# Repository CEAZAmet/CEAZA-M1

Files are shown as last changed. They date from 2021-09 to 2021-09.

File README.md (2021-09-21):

# Welcome to CEAZA-M1!
Wireless communication and memory backup expansion board for CEAZA MEGA.
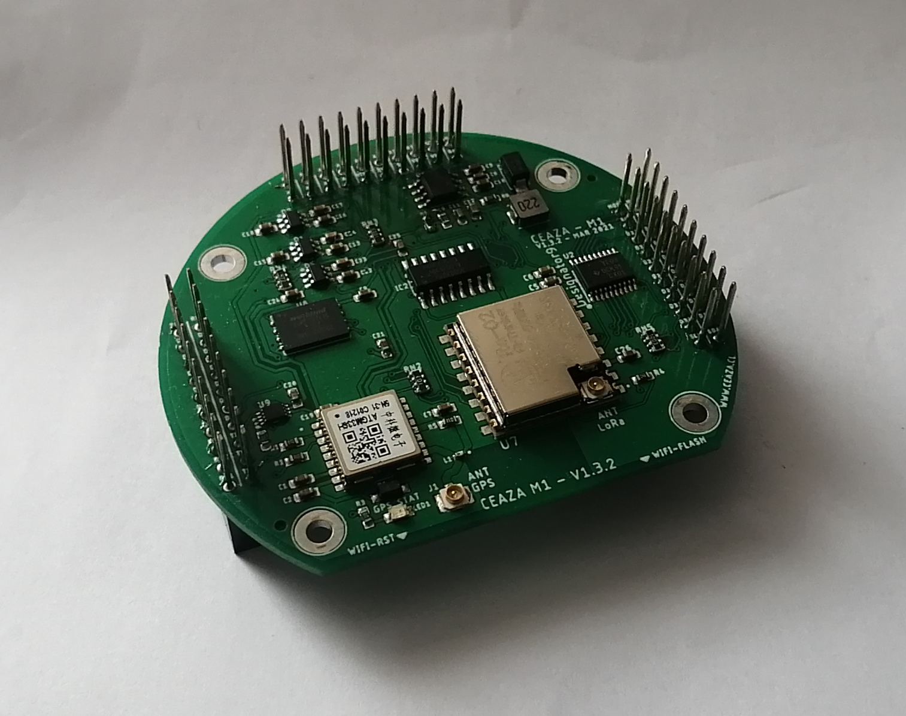
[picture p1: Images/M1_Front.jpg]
CEAZA M1 Board


## What is the CEAZA M1?

This design is an expansion board for CEAZA MEGA datalogger, which add the local wireless comumunication capability to the system.
The board Design integrates:
* An Ra-02 Ai-Thinker for 410-525MHz or Ra-01SH for 803MHz~930MHz LoRa Radio module.
* An ATGM336H-5N-31 GNSS GPS BDS positioning and navigation module.
* An ESP-12E WiFi module.
* A W25N01GVZEIG 1G-bit serial nand flash memory for redundant data storage.

All modules integratred are equiped with its respective power switch and power supply controlled by firmware for energy save when low power consumtions are required.
An on board jumper is included, ready to solder when the backup power source is required for GNSS module from permanent 3.3V available from CEAZA MEGA board, which increases 10uA the system power consumption.

The GNSS and WiFi modules share the same MCU UART2 thought an 74HC4052D analog multiplexer, which is controlled by firmware.

This board is pin compatible and should be connected to the CEAZA MEGA system to proper work.

## Documentation
A comprehensive documentation for well undertand, use or modify the CEAZA M1 board is available in our Wiki. In adition, we share with you the schematics diagrams, adns Arduino example codes.

## Quickstart guide
Install the M1 board in the CEAZA MEGA's bottom, make certain connection throuhg the boards by three 2 x 10 pin header terminals is rigth. 
Attach GNSS and LoRa antennas to the board, connect the power source 7 to 14 Vdc to the system.
Connect the CEAZA MEGA main board system to the host PC by mini-USB connector, open the Arduino ide software, select the Arduino Mega board and the correspondign COM port.

Open any of examples scketches and upload to the board.

# Contact and support
For all kinds of inquiries, please contact me to my e-mail address: adrian.gallardo@ceaza.cl

# Contributing
You are welcome to contribute to the development or improvement of M1 hardware design or example application codes. Feel free to submit a new pull request via github.

# Academic Context

# Licensing

# Disclaimer
Use M1 board and examples code at your own risk. We do not encourage any malicious use of our board.

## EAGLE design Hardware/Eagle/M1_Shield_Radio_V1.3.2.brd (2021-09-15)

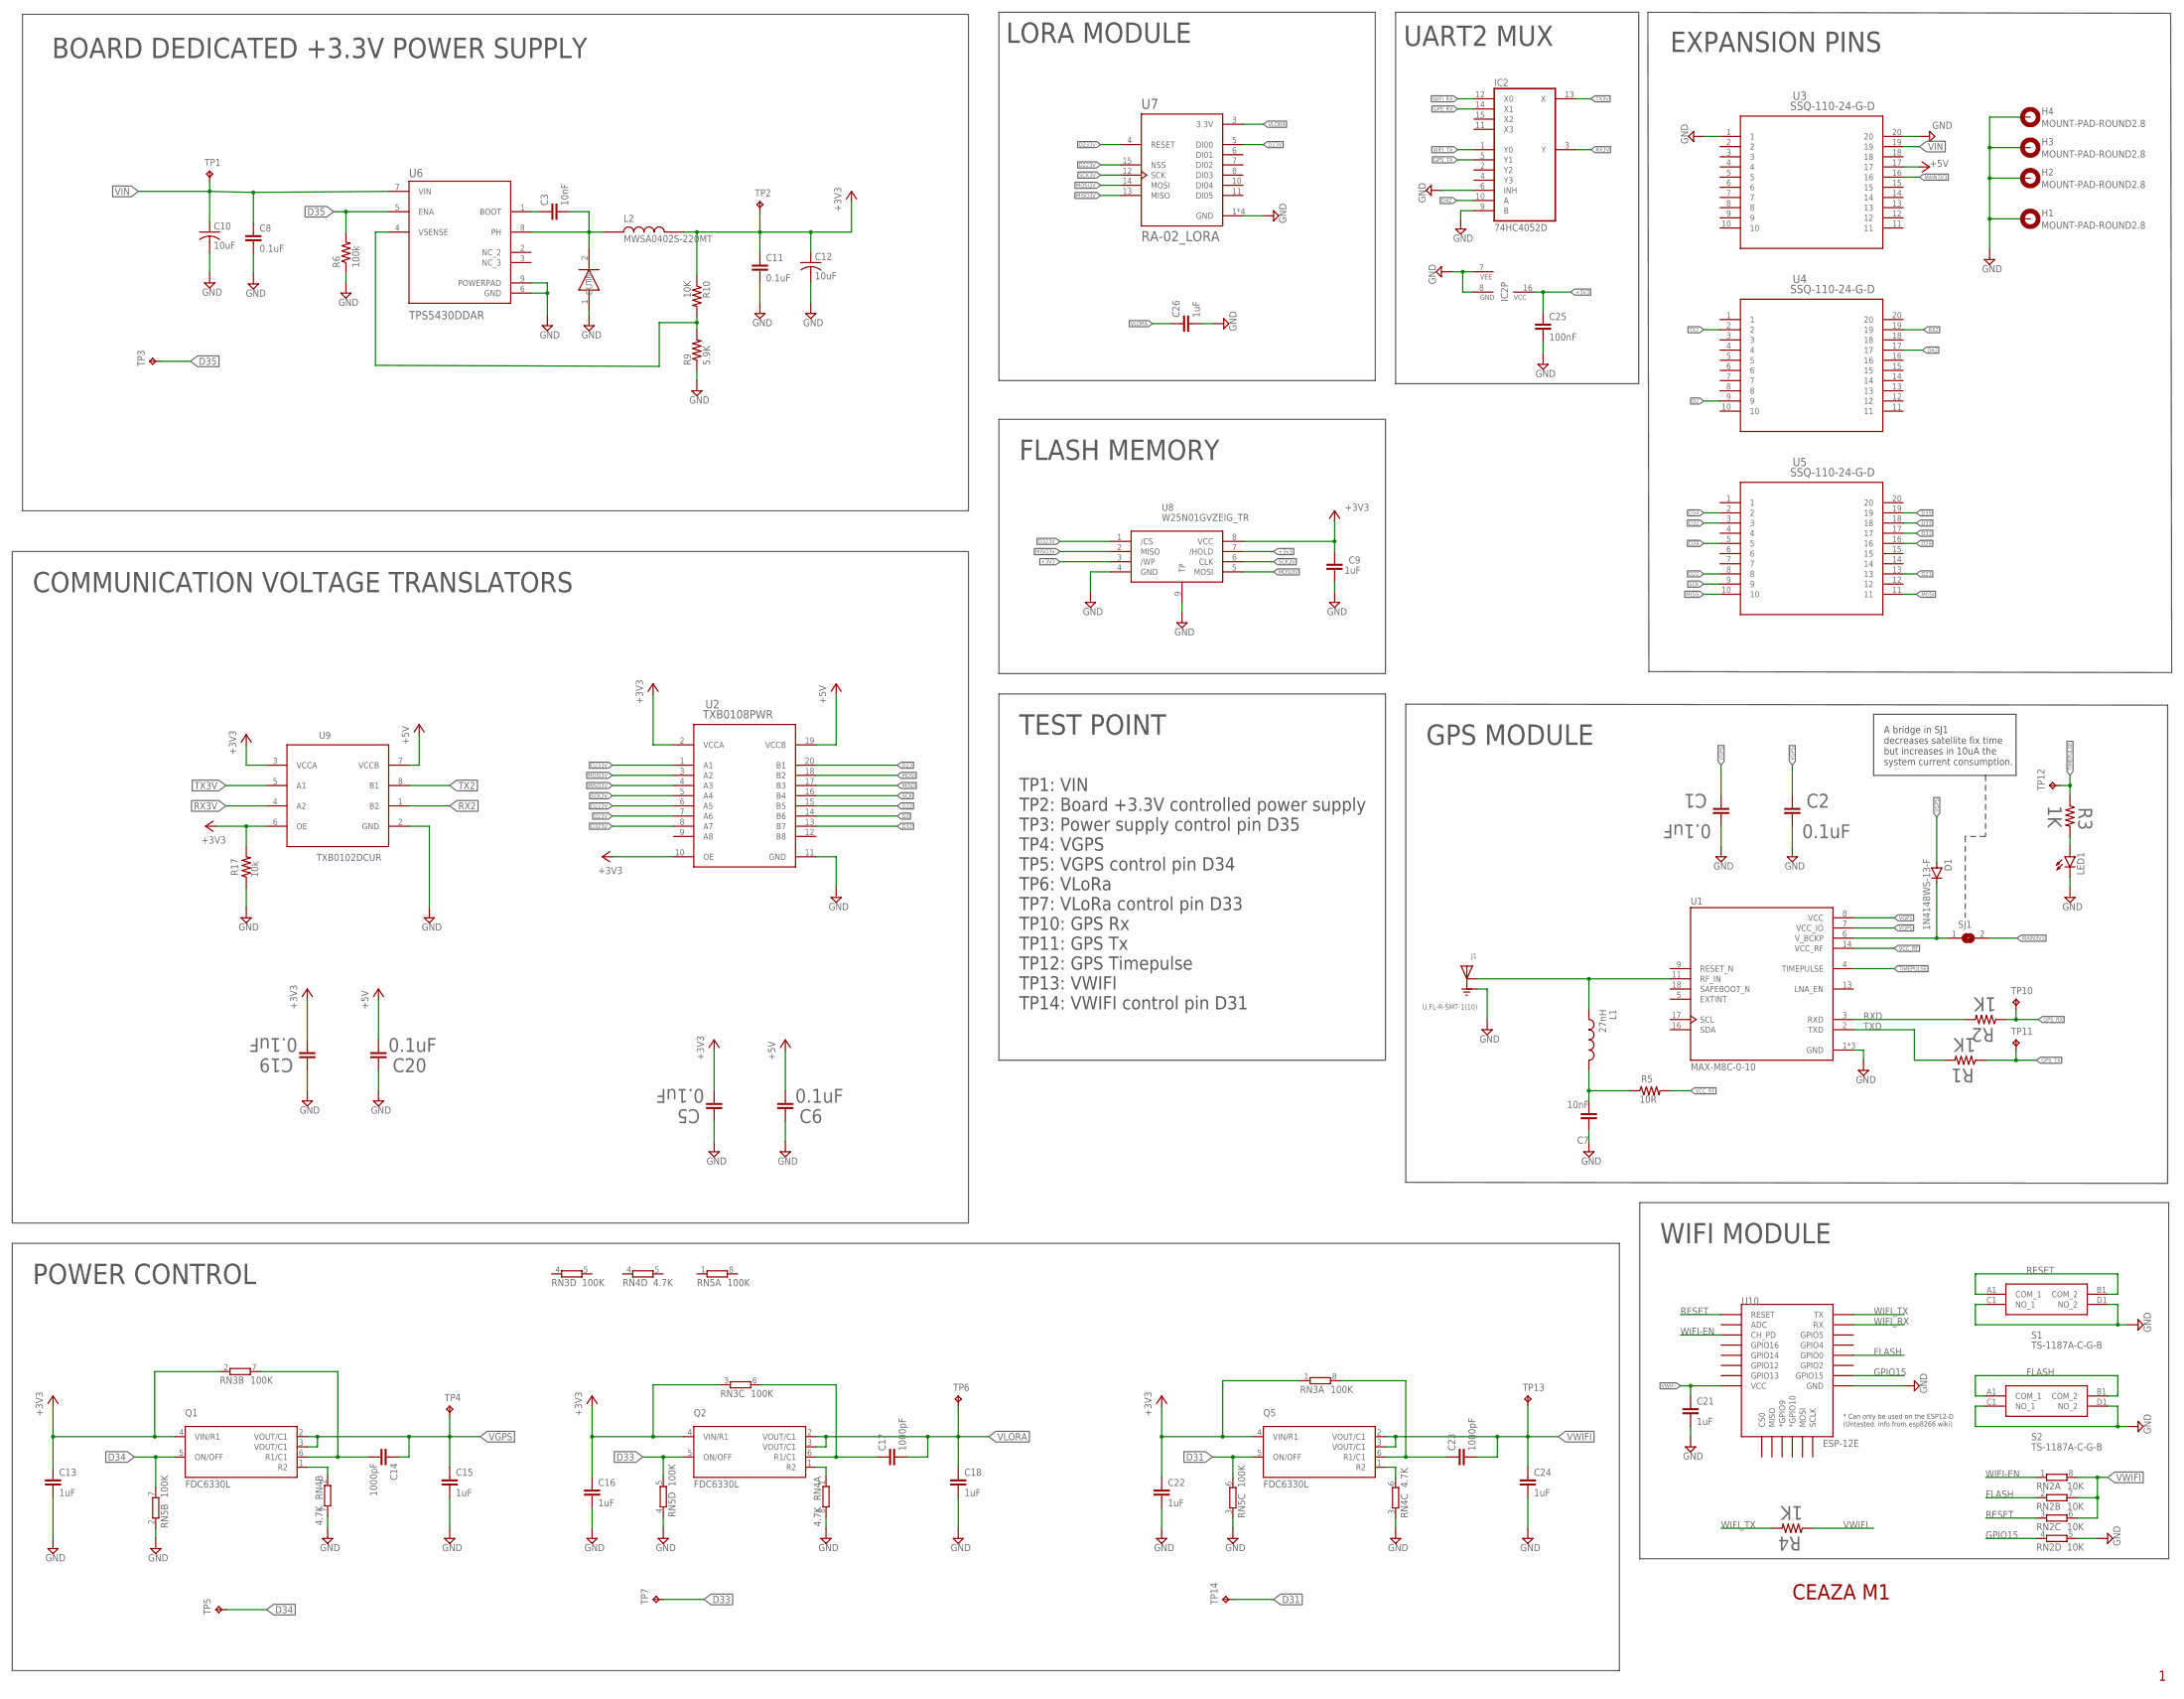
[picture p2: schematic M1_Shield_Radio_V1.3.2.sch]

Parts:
C1, C2, C5, C6, C8, C11, C19, C20: 0.1uF; C0603K
C3, C7: 10nF; C0603K
C9, C13, C15, C16, C18, C21, C22, C24, C26: 1uF; C0603K
C10, C12: 10uF; C0603K
C14, C17, C23: 1000pF; C0603K
C25: 100nF; C0603K
D1: 1N4148WS-13-F; SOD323-W
H1, H2, H3, H4: MOUNT-PAD-ROUND2.8; 2,8-PAD
IC2: 74HC4052D; SO16
J1: U.FL-R-SMT-1(10); HRS_U.FL-R-SMT-1(10)
L1: 27nH; INDC1005X55N
L2: MWSA0402S-220MT
LED1: LEDCHIP-LED0805; CHIP-LED0805
Q1, Q2, Q5: FDC6330L; SOT95P280X110-6N
R1, R2, R3, R4: 1K; R0603
R5: 10R; R0603
R6: 100k; R0603
R9: 5.9K; R0603
R10: 10K; R0603
R17: 10k; R0603
RN2: 10K; 0603-ARV
RN3, RN5: 100K; 0603-ARV
RN4: 4.7K; 0603-ARV
S1, S2: TS-1187A-C-G-B; TS1187ACGB
SJ1: SJ
TP1, TP2, TP3, TP4, TP5, TP6, TP7, TP10, TP11, TP12, TP13, TP14: TPB1,27; B1,27
U1: MAX-M8C-0-10; XCVR_MAX-M8C-0-10
U2: TXB0108PWR; PW0020A_N
U3, U4, U5: SSQ-110-24-G-D; 1-215307-0
U6: TPS5430DDAR; CONV_TPS5430DDAR
U7: RA-02_LORA; MODULE_RA-02_LORA
U8: W25N01GVZEIG_TR; W25N01GVZEIGTR
U9: TXB0102DCUR; DCU0008A_L
U10: ESP-12E; ESP12E-SMD
U$1: SMA-SS34

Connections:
+3V3: C5.2, C9.1, C11.1, C12.1, C13.1, C16.1, C19.2, C22.1, C25.1, IC2.16 (VCC), L2.P$2, Q1.4 (VIN/R1), Q2.4 (VIN/R1), Q5.4 (VIN/R1), R10.1, R17.2, RN3.1, RN3.2 (1), RN3.3 (1), TP2.TP, U2.2 (VCCA), U2.10 (OE), U8.3 (/WP), U8.7 (/HOLD), U8.8 (VCC), U9.3 (VCCA), U9.6 (OE)
+5V: C6.2, C20.2, U2.19 (VCCB), U3.17, U9.7 (VCCB)
D2: U2.14 (B6), U4.9
D22: U2.15 (B5), U5.8
D23: U2.20 (B1), U5.13
D23V: U2.7 (A6), U7.5 (DI00)
D28: U5.5
D29: U5.16
D31: Q5.5 (ON/OFF), RN5.6 (2), TP14.TP, U5.17
D32: U2.13 (B7), U5.3
D33: Q2.5 (ON/OFF), RN5.5 (2), TP7.TP, U5.18
D34: Q1.5 (ON/OFF), RN5.7 (2), TP5.TP, U5.2
D35: R6.2, TP3.TP, U5.19, U6.5 (ENA)
D42: IC2.10 (A), U4.17
D223V: U2.6 (A5), U7.15 (NSS)
D233V: U2.1 (A1), U7.4 (RESET)
D323V: U2.8 (A7), U8.1 (/CS)
FLASH: RN2.2 (1), S2.A1 (COM_1), S2.B1 (COM_2), U10.GPIO0
GND: C1.1, C2.1, C5.1, C6.1, C7.1, C8.2, C9.2, C10.2, C11.2, C12.2, C13.2, C15.2, C16.2, C18.2, C19.1, C20.1, C21.2, C22.2, C24.2, C25.2, C26.2, H1.B2,8, H2.B2,8, H3.B2,8, H4.B2,8, IC2.6 (INH), IC2.7 (VEE), IC2.8 (GND), IC2.9 (B), J1.1 (GND), J1.3 (GND), LED1.C, R6.1, R9.1, R17.1, RN2.5 (2), RN4.3 (1), RN4.7 (2), RN4.8 (2), RN5.2 (1), RN5.3 (1), RN5.4 (1), S1.C1 (NO_1), S1.D1 (NO_2), S2.C1 (NO_1), S2.D1 (NO_2), U1.1 (GND), U1.10 (GND), U1.12 (GND), U2.11 (GND), U3.1, U3.20, U6.6 (GND), U6.9 (POWERPAD), U7.1 (GND), U7.2 (GND), U7.9 (GND), U7.16 (GND), U8.4 (GND), U8.9 (TP), U9.2 (GND), U10.GND, U$1.1 (IN)
GPIO15: RN2.4 (1), U10.GPIO15
GPS_RX: IC2.14 (X1), R2.1, TP10.TP
GPS_TX: IC2.5 (Y1), R1.1, TP11.TP
MAIN3V3: SJ1.2, U3.16
MISO: U2.17 (B3), U5.10
MISO3V: U2.4 (A3), U7.13 (MISO), U8.2 (MISO)
MOSI: U2.18 (B2), U5.11
MOSI3V: U2.3 (A2), U7.14 (MOSI), U8.5 (MOSI)
unnamed: Q5.1 (R2), RN4.6 (2)
unnamed: LED1.A, R3.2
unnamed: J1.2 (SIG), L1.1, U1.11 (RF_IN)
unnamed: C7.2, L1.2, R5.1
unnamed: C3.1, U6.1 (BOOT)
unnamed: C14.2, Q1.6 (R1/C1), RN3.7 (2)
unnamed: C23.1, Q5.6 (R1/C1), RN3.8 (2)
unnamed: Q1.1 (R2), RN4.2 (1)
unnamed: Q2.1 (R2), RN4.1
unnamed: C17.1, Q2.6 (R1/C1), RN3.6 (2)
unnamed: D1.C, SJ1.1, U1.6 (V_BCKP)
unnamed: C3.2, L2.P$1, U6.8 (PH), U$1.2 (OUT)
RESET: RN2.3 (1), S1.A1 (COM_1), S1.B1 (COM_2), U10.RESET
RX2: U4.19, U9.1 (B2)
RX3V: IC2.3 (Y), U9.4 (A2)
RXD: R2.2, U1.3 (RXD)
SCK: U2.16 (B4), U5.9
SCK3V: U2.5 (A4), U7.12 (SCK), U8.6 (CLK)
TIMEPULSE: R3.1, TP12.TP, U1.4 (TIMEPULSE)
TX2: U4.2, U9.8 (B1)
TX3V: IC2.13 (X), U9.5 (A1)
TXD: R1.2, U1.2 (TXD)
VCC_RF: R5.2, U1.14 (VCC_RF)
VFB: R9.2, R10.2, U6.4 (VSENSE)
VGPS: C1.2, C2.2, C14.1, C15.1, D1.A, Q1.2 (VOUT/C1), Q1.3 (VOUT/C1), TP4.TP, U1.7 (VCC_IO), U1.8 (VCC)
VIN: C8.1, C10.1, TP1.TP, U3.19, U6.7 (VIN)
VLORA: C17.2, C18.1, C26.1, Q2.2 (VOUT/C1), Q2.3 (VOUT/C1), TP6.TP, U7.3 (3.3V)
VWIFI: C21.1, C23.2, C24.1, Q5.2 (VOUT/C1), Q5.3 (VOUT/C1), R4.1, RN2.6 (2), RN2.7 (2), RN2.8 (2), TP13.TP, U10.VCC
WIFI-EN: RN2.1, U10.CH_PD
WIFI_RX: IC2.12 (X0), U10.RXD0 (RX)
WIFI_TX: IC2.1 (Y0), R4.2, U10.TXD0 (TX)

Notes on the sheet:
BOARD DEDICATED +3.3V POWER SUPPLY
LORA MODULE
FLASH MEMORY
POWER CONTROL
GPS MODULE
COMMUNICATION VOLTAGE TRANSLATORS
EXPANSION PINS
TP1: VIN TP2: Board +3.3V controlled power supply TP3: Power supply control pin D35 TP4: VGPS TP5: VGPS control pin D34 TP6: VLoRa TP7: VLoRa control pin D33 TP10: GPS Rx TP11: GPS Tx TP12: GPS Timepulse TP13: VWIFI TP14: VWIFI control pin D31
TEST POINT
UART2 MUX
WIFI MODULE
A bridge in SJ1 decreases satellite fix time but increases in 10uA the system current consumption.
CEAZA M1

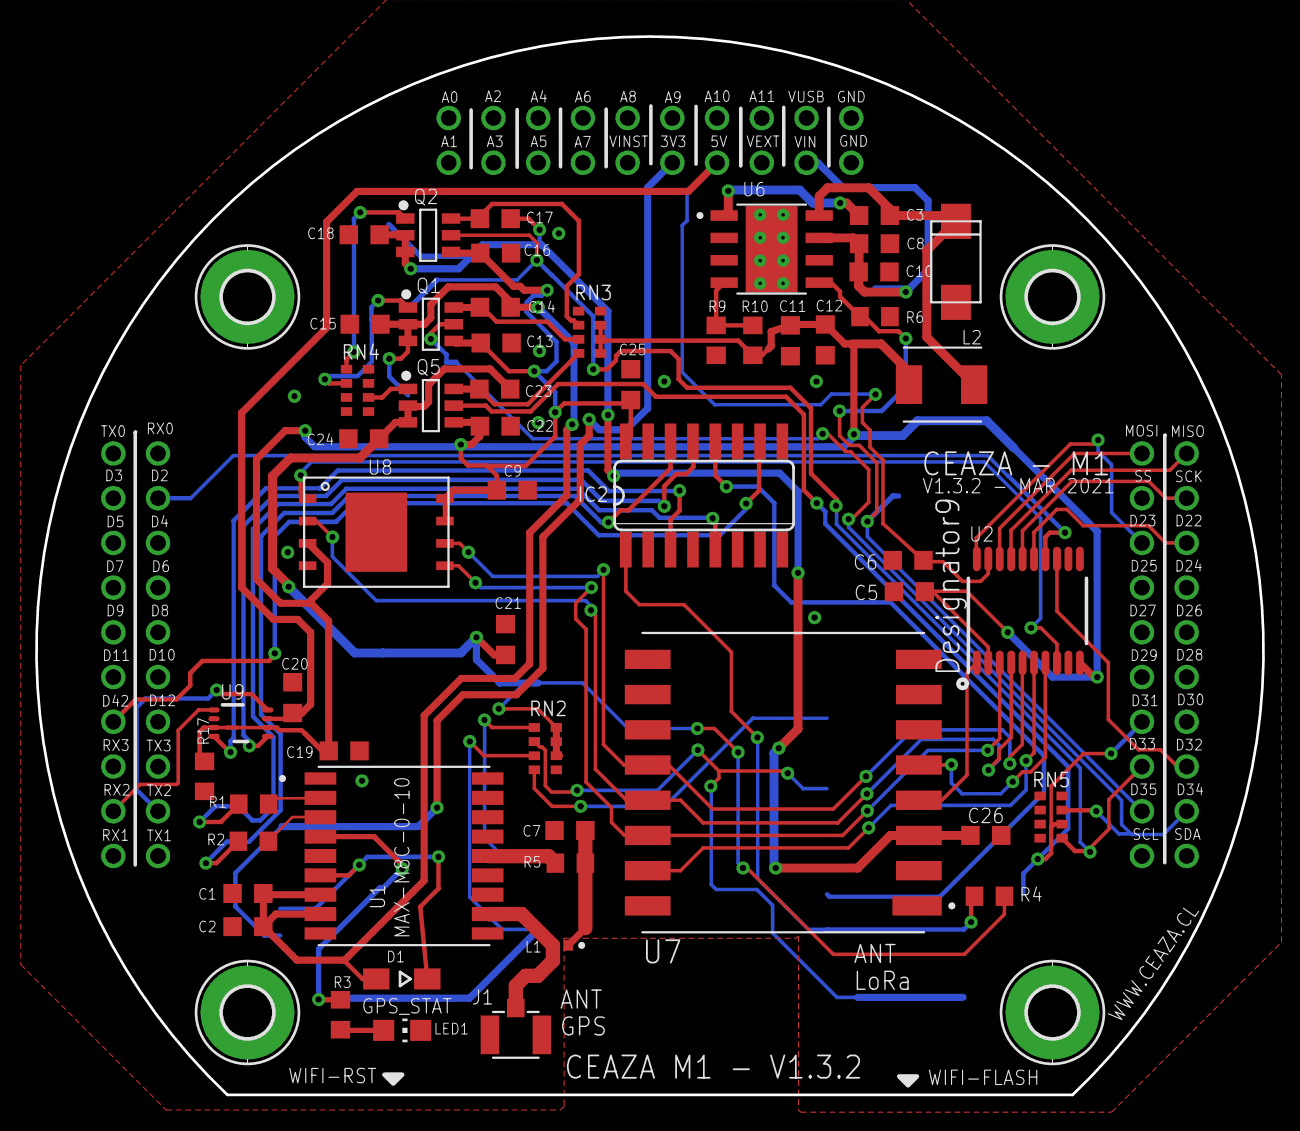
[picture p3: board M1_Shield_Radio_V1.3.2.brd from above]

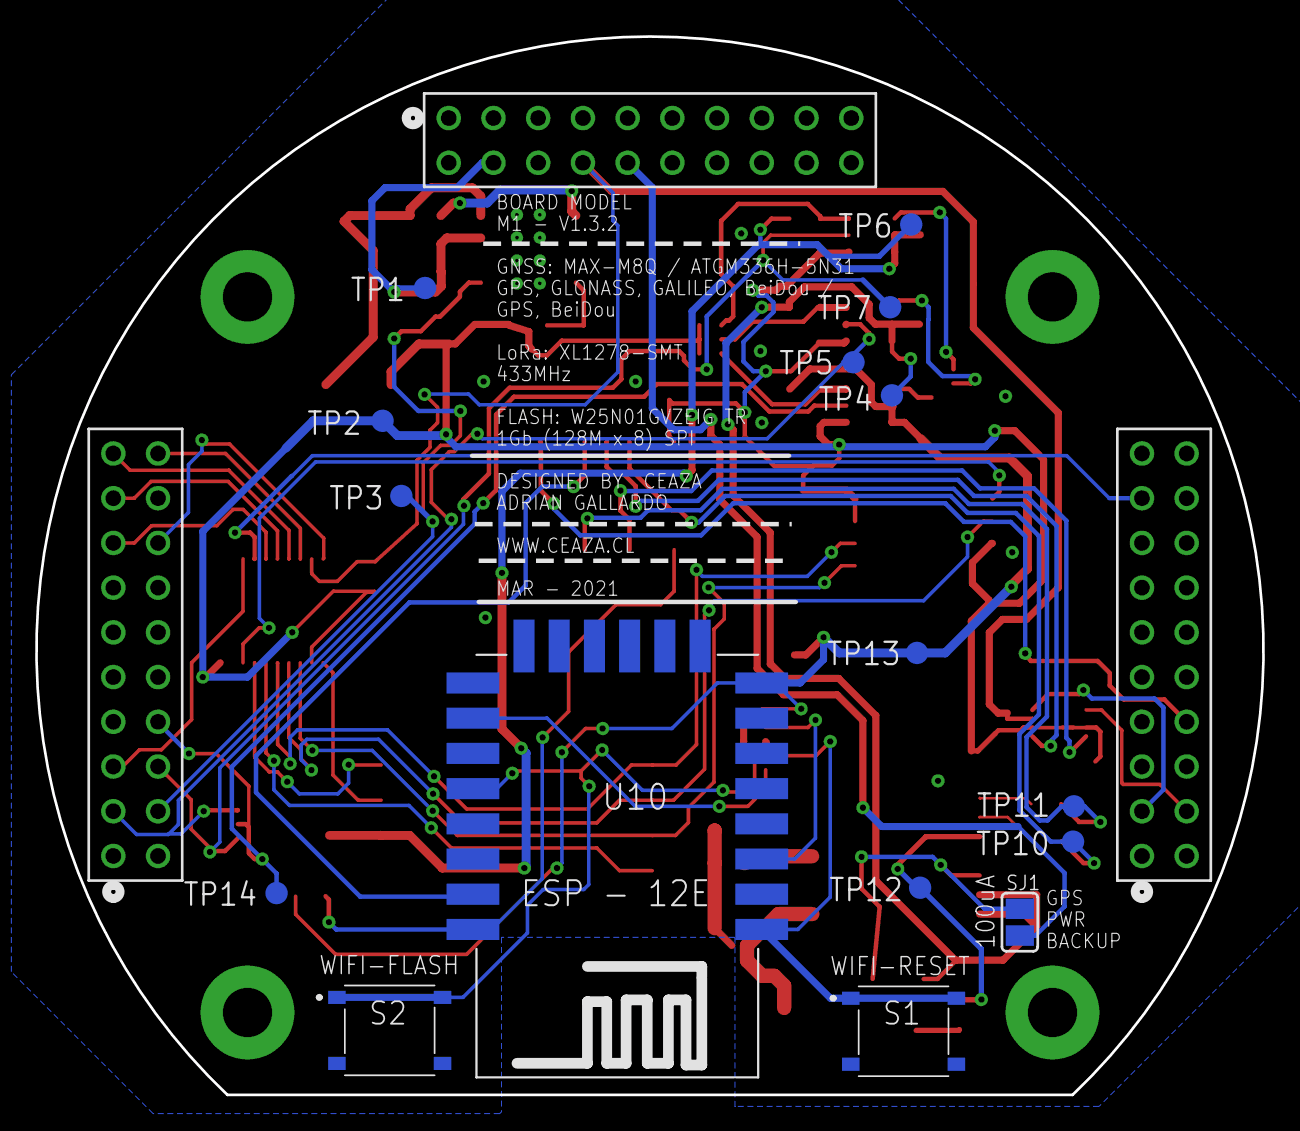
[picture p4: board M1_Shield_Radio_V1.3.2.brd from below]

Board: 2 copper layers, 69.7 x 60.1 mm, 77 parts (19 on the bottom side), 56 nets.

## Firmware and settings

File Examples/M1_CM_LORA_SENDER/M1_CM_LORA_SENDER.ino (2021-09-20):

/*
 * This sketch is an application example of LoRa.h and LowPwer.h with a 433MHz LoRa module
 * for data transmitting and go to sleep in CEAZA MEGA + M1 system
 * Is highly recommend do not use the M1 module without LoRa and GNSS antenas connected
 * to avoid damage the respective modules.
 * 
 * You have to intall LoRa library
 * https://github.com/sandeepmistry/arduino-LoRa
 * 
 * and LowPower library
 * https://github.com/rocketscream/Low-Power
 * 
 * Remember to select the "Arduino Mega or Mega2560" board for CEAZA MEGA
 */
#include <SPI.h>
#include <LoRa.h>
#include "LowPower.h"

// Pin definition
#define M1_3V3_EN_PIN   35
#define M1_VLORA_EN_PIN 33
#define LORA_SS_PIN     22
#define LORA_RESET_PIN  23
#define LORA_DIO0_PIN   2
#define FLASH_SS_PIN    32
#define SD_SS_PIN       53
#define LED_PIN         13

// LoRa setup definition
#define LORA_FREC       433E6   //(`433E6`, `866E6`, `915E6`)
#define LORA_SF         9       //6 to 12
#define LORA_TX_POW     18      //2 to 20
#define LORA_BANDWIDTH  125E3   //`7.8E3`, `10.4E3`, `15.6E3`, `20.8E3`, `31.25E3`, `41.7E3`, `62.5E3`, `125E3`, and `250E3`.

// Message counter
int counter = 0;

void setup() {
  // MCU I/O definition
  pinMode(FLASH_SS_PIN,OUTPUT);digitalWrite(FLASH_SS_PIN,HIGH);       // SPI Flash communication disabled
  pinMode(SD_SS_PIN,OUTPUT);digitalWrite(SD_SS_PIN,HIGH);             // SPI microSD communication disabled
  pinMode(LED_PIN,OUTPUT);digitalWrite(LED_PIN,LOW);                  // Built in LED off
  pinMode(M1_3V3_EN_PIN,OUTPUT);digitalWrite(M1_3V3_EN_PIN,HIGH);     // dedicated M1 3.3V power supply on 
  delay(10);                                                          // step down converter Start time
  pinMode(M1_VLORA_EN_PIN,OUTPUT);digitalWrite(M1_VLORA_EN_PIN,HIGH); // turn-on LoRa module

  Serial.begin(115200);
  Serial.println("\nM1 CEAZA Mega LoRa Sender");
  
  LoRa.setPins(LORA_SS_PIN, LORA_RESET_PIN, LORA_DIO0_PIN);
  Serial.print("LORA_TX_POW,");Serial.print(LORA_TX_POW);
  Serial.print(",LORA_FREC_MHz,");Serial.print(LORA_FREC/1000000);
  Serial.print(",LORA_SF,");Serial.print(LORA_SF);
  Serial.print(",LORA_BANDWIDTH_KHz,");Serial.print(LORA_BANDWIDTH/1000);
  Serial.println();

  // Begin LoRa module
  if (!LoRa.begin(433E6)) {    
    Serial.println("Starting LoRa failed!");    
    while (1);
  }
  LoRa.setTxPower(LORA_TX_POW);
  LoRa.setSpreadingFactor(LORA_SF);
  LoRa.setSignalBandwidth(LORA_BANDWIDTH);

  // Once the LoRa module is not in use the module is turn-off to reduce the power consumption
  digitalWrite(M1_VLORA_EN_PIN,LOW);  // Turn-off the LoRa module
  digitalWrite(M1_3V3_EN_PIN,LOW);    // Turn-off the M1 +3V3 power supply
}

void loop() {
  // Turn-on LoRa module
  digitalWrite(M1_3V3_EN_PIN,HIGH);delay(10);
  digitalWrite(M1_VLORA_EN_PIN,HIGH);

  // LoRa Module init. it must be initializaed every time is turned on
  if (!LoRa.begin(433E6)) {    Serial.println("Starting LoRa failed!"); }
  else{
    digitalWrite(LED_PIN,HIGH);        // LED is turn on while the module is transmitting data
    LoRa.setTxPower(LORA_TX_POW);
    LoRa.setSpreadingFactor(LORA_SF);
    LoRa.setSignalBandwidth(LORA_BANDWIDTH);
    
    Serial.print("Sending packet: "); 
    Serial.println(counter);

    // send packet
    LoRa.beginPacket();
    LoRa.print("hello ");
    LoRa.print(counter);    
    LoRa.endPacket();
  
    counter++;
    
    digitalWrite(LED_PIN,LOW);      // Turn off transmitting LED
  }
  
  // Turn-off LoRa module to save energy
  digitalWrite(M1_VLORA_EN_PIN,LOW);
  digitalWrite(M1_3V3_EN_PIN,LOW);

  // Go to sleep 4S
  Serial.flush();
  LowPower.powerDown(SLEEP_4S, ADC_OFF, BOD_OFF); 
}

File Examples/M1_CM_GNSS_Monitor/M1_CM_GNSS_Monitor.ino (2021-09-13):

/*  
 * For this codee you have to connect an M1 board to a CEAZA MEGA borad.
 * To program the CEAZA MEGA borad you have to select the "Arduino Mega or Mega 2560" board.
 * 
 * This code acts as a M1's GNSS module monitor through CEAZA MEGA board.
 * You can see by serial monitor all messages sent by the GNSS module and also send commands to the module.
 * 
 *  https://github.com/adgallardo/CEAZA-M1
 *  
 */
#define M1_3V_EN_PIN      35
#define M1_VGPS_EN_PIN    34
#define M1_UART2_MUX_PIN  42
#define GNSS_SERIAL Serial2

void setup() {
  // initialize serial ports:
  Serial.begin(115200);     // Serial monitor serial port
  GNSS_SERIAL.begin(9600);  // GNSS module serial port at 9600bps by default

  // Activate GNSS module and establish communication rute
  pinMode(M1_3V_EN_PIN,OUTPUT);digitalWrite(M1_3V_EN_PIN,HIGH);         // +3.3V power supply on board activated
  delay(10);                                                            // +3.3V power supply start time 
  pinMode(M1_VGPS_EN_PIN,OUTPUT);digitalWrite(M1_VGPS_EN_PIN,HIGH);     // Turn GNSS module on
  pinMode(M1_UART2_MUX_PIN,OUTPUT);digitalWrite(M1_UART2_MUX_PIN,HIGH); // Select GNSS module in UART2 multiplexer
}

void loop() {
  // Show by serial monitor data from GNSS module
  if (GNSS_SERIAL.available()) {
    int inByte = GNSS_SERIAL.read();
    Serial.write(inByte);
  }

  // Send to GNSS module any byte send by serial monitor
  if (Serial.available()) {
    int inByte = Serial.read();
    GNSS_SERIAL.write(inByte);
  }
}
